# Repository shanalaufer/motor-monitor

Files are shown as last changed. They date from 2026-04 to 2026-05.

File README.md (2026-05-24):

# Motor Health Monitor
### AI-powered predictive maintenance system for electric motors


👉 [API docs (Swagger UI)](https://motor-fault-api-f7r8.onrender.com/docs)

---

## What this is

An end-to-end system that detects motor bearing faults before they cause failure. It collects vibration data from an accelerometer, extracts signal features using FFT-based processing, and runs a machine learning model to classify motor health in real time — displayed on a live web dashboard.

This is the same concept used in industrial predictive maintenance systems at manufacturing plants, wind farms, and data centers — where unplanned motor failures can cost thousands of dollars per minute of downtime.

---

## Live demo

👉 [Open the live dashboard](https://motor-monitor-gtmdausuctqgflvd5xteux.streamlit.app/)

Use the sidebar to switch between healthy and faulty motor modes and watch the FFT, health score, and status banner update in real time.

---

## System architecture
```
Vibration sensor (MPU-6050)
        ↓
Edge node (ESP32) — samples at 500Hz over I2C
        ↓
Feature extraction — FFT, RMS, crest factor, fault frequency energy
        ↓
REST API (FastAPI) — hosted on Render
        ↓
Random Forest + Autoencoder — dual model inference
        ↓
Live dashboard (Streamlit Cloud) — health score, signal plots, alerts
```

---

## Key results

- 96.7% accuracy (RF) and 90.0% accuracy (AE) on 297 real motor samples
- Health score drops from 95-100% to 0-43% when physical imbalance introduced
- Top features: crest_factor (31%), RMS (30%)
- Fault detection latency: <2 seconds from sensor to alert
- Autoencoder trained on healthy samples only — detects faults via reconstruction error
- 3-axis preprocessing: Butterworth bandpass (10-200Hz) + Welch PSD axis selection

---
## Model comparison — Random Forest vs Autoencoder

| | Random Forest | Autoencoder |
|---|---|---|
| Type | Supervised | Unsupervised |
| Training data needed | Labeled healthy + faulty | Healthy only |
| Accuracy | 96.7% | 90.0% |
| Missed faults | 0 | 0 |
| False alarms | 0 | 1 |
| Faulty error ratio | N/A | 36.9x higher than healthy |

**Key insight:** The autoencoder was trained only on healthy samples — it never saw a single fault example. Yet it detected faulty motors with high accuracy because the reconstruction error for faulty signals was significantly higher than healthy signals.

**Reconstruction error ratio after retraining (v1 model — historical):**
After collecting more healthy data (48 → 106 samples) and retraining, the ratio dropped from 66x to 36.9x — but the system became significantly more reliable on the live motor. Healthy reconstruction error dropped from 0.53 to 0.18, meaning the model learned a tighter, more accurate definition of normal. The tradeoff between sensitivity and false alarm rate is a core challenge in anomaly detection — more healthy data improved real-world reliability at the cost of a slight reduction in the error ratio.

**Unexpected finding:** Energy at 100Hz was actually higher in healthy motors (0.385) than faulty ones (0.290) — the opposite of what simulation predicted. Real motor behavior doesn't always match simulation assumptions. This is why collecting real labeled data matters.

**Why the autoencoder matters for real deployment:** A Random Forest requires fault examples to train on — meaning you need to wait for something to break or deliberately damage equipment. The autoencoder only needs normal operation data, which every system already has from day one.

## API layer

The system runs as three separate services communicating through a REST API:
ESP32 → receiver.py → POST /predict → api.py → stores result
↓
dashboard.py → GET /health every 2s → live display

**API endpoints:**

| Endpoint | Method | What it does |
|---|---|---|
| `/` | GET | Confirms API is running |
| `/health` | GET | Returns latest motor reading |
| `/history` | GET | Returns last 100 readings |
| `/predict` | POST | Accepts features, runs both models, returns results |
| `/faults` | GET | Returns all fault detection events |
| `/trends?hours=24` | GET | Average health scores over a time period |
| `/stats` | GET | Total readings, fault counts, first/last reading time |
| `/export/csv` | GET | Download full history as CSV |

**How to run the system:**

The API is deployed on Render at: https://motor-fault-api-f7r8.onrender.com

To run the system:
- python3 receiver.py — streams ESP32 data to the hosted API
- streamlit run dashboard.py — starts the local dashboard

**Dashboard modes:**
- **Live sensor** — reads from ESP32 via receiver.py → api.py
- **Simulation** — generates signals locally, sends through API for prediction

## How it works

**Signal processing:**
Motor vibration is sampled at 500Hz across all 3 axes (X, Y, Z), preprocessed with DC offset removal, a Butterworth bandpass filter (10-200Hz), and Welch PSD axis selection. The FFT decomposes the raw signal into frequency components — a healthy motor shows one dominant peak at its rotation frequency (50Hz). Motor imbalance creates energy at harmonics of the rotation frequency (100Hz, 150Hz) and elevated crest factor — detected by the ML model in real time. Five features are extracted from each signal window: RMS amplitude, peak value, crest factor, and energy at 50Hz, 100Hz, and 150Hz.

**Machine learning:**
A Random Forest classifier (100 trees) was trained on 1000 labeled samples — 500 healthy, 500 faulty — with an 80/20 train/test split. The model outputs a fault probability which is converted to a 0-100% health score. The model was chosen for its interpretability and robustness on small tabular datasets.

**Why crest factor matters:**
Bearing faults create sharp impact spikes in the vibration signal. Crest factor (peak ÷ RMS) is sensitive to these spikes — a healthy motor has a crest factor around 1.4, while an impact-type fault can push it above 3.0. This is a standard diagnostic metric in industrial vibration analysis.

---
## Hardware integration

The system runs on an ESP32-WROOM microcontroller connected to an MPU-6050 MEMS accelerometer over I2C. The ESP32 samples vibration at 500Hz and streams data over WiFi to the Python pipeline in real time.

**Hardware stack:**
- ESP32-WROOM — microcontroller running MicroPython, handles I2C and WiFi
- MPU-6050 — 3-axis MEMS accelerometer, mounted directly on motor body
- L298N — motor driver module, controls DC motor speed and direction
- Small DC hobby motor — test subject for vibration analysis

**PCB Design:**
Custom PCB designed in KiCad to replace the breadboard prototype. The schematic includes all three main components (ESP32-WROOM-32E, MPU-6050, L298N) with proper decoupling capacitors and power distribution. KiCad design files are included in the `motor monitor pcb/` folder.

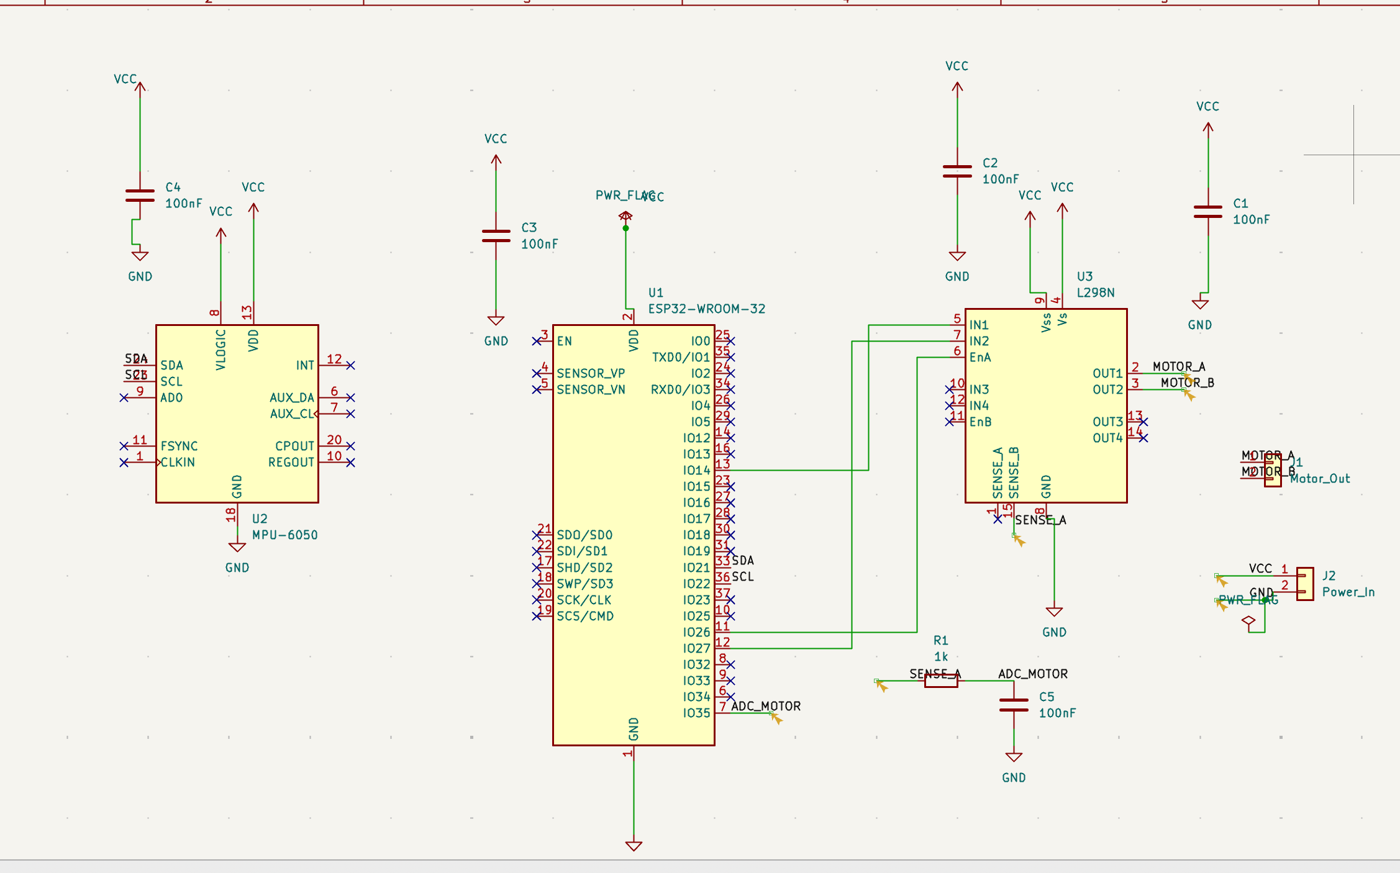
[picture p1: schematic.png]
Schematic


**Signal conditioning:**
A hardware RC anti-aliasing filter (R = 10kΩ, C = 68nF, fc = 234Hz) sits between the sensor output and the ESP32 ADC input. This prevents frequency aliasing by attenuating signals above the Nyquist frequency (250Hz at 500Hz sampling rate) before digitization — a problem that cannot be corrected in software after sampling. This complements the software Butterworth bandpass filter in the preprocessing pipeline. Two-stage filtering: hardware prevents aliasing, software removes noise.

**What I learned from real hardware:**

The sim-to-real gap is real. The simulation-trained model performed reasonably on real data but highlighted two key challenges:

1. **Gravity offset** — the accelerometer measures 1g of gravity as a DC offset that needed to be removed before feature extraction using mean subtraction
2. **Fault signature differences** — simulated bearing faults (clean 120Hz sine wave) don't perfectly match real imbalance faults, which show up more in crest factor than in fault frequency energy

**Update:** Real labeled data was collected from the physical motor — 66 healthy samples and 57 faulty samples (imbalance created by asymmetric mass on shaft). Model retrained on real data achieved 100% accuracy with crest factor as the most important feature.

## Results on real hardware

**Healthy motor:** 95-100% health score consistently with sensor mounted on motor body

**Fault detection:** Physical imbalance (asymmetric mass on shaft) successfully detected — system flagged FAULT DETECTED with health score dropping significantly

**Key finding — sim-to-real gap:** Original model trained on simulated 120Hz bearing fault signal did not generalize to real imbalance faults. Real imbalance creates energy at harmonics of rotation frequency (100Hz, 150Hz) and elevated crest factor — not a clean 120Hz signal. Model was retrained with updated imbalance simulation and successfully detected real physical faults.

**Lesson:** The gap between simulation and real sensor data is a genuine engineering challenge. Gravity offset removal, consistent sensor mounting, and fault-type-specific feature engineering were all required to bridge it.

## Tech stack

| Layer | Technology |
|---|---|
| Signal processing | Python, NumPy, SciPy (FFT) |
| Machine learning | scikit-learn (Random Forest) |
| Deep learning | PyTorch (Autoencoder) |
| Edge firmware | MicroPython on ESP32 |
| Sensor | MPU-6050 accelerometer over I2C |
| Backend API | FastAPI |
| Database | SQLite (via Render) |
| Dashboard | Streamlit |
| Deployment | Streamlit Cloud + Render |

---

## Project structure
```
motor-monitor/
├── signal_sim.py          # Signal simulation and FFT visualization
├── generate_dataset.py    # Dataset generation (1000 labeled samples)
├── train_model.py         # Model training and evaluation (simulation)
├── train_real.py          # Retrain on real motor data
├── train_v2.py            # Retrain on preprocessed 3-axis data
├── receiver.py            # Receives ESP32 data, runs ML model
├── dashboard.py           # Live Streamlit dashboard
├── preprocessor.py        # 3-axis preprocessing pipeline
├── autoencoder.py         # PyTorch autoencoder training
├── api.py                 # FastAPI backend
├── motor_dataset.csv      # Generated training dataset
├── real_data.csv          # Real motor sensor data (labeled)
├── real_data_v2.csv       # 297 samples (202 healthy + 95 faulty)
├── raw_healthy.npy        # Raw 3-axis healthy bursts
├── raw_faulty.npy         # Raw 3-axis faulty bursts
├── motor_model.pkl        # Trained Random Forest model
├── autoencoder.pth        # Trained autoencoder weights
├── scaler.pkl             # Feature scaler for autoencoder
├── motor_model_v2.pkl         # RF v2 model
├── autoencoder_v2.pth         # AE v2 weights
├── scaler_v2.pkl              # Feature scaler v2
├── autoencoder_threshold_v2.pkl  # AE threshold v2
└── requirements.txt       # Python dependencies

```
---

## Testing & reliability

The project includes a full automated test suite covering the live API, the preprocessing pipeline, and the ML models — 121 tests across three files. Tests run against the real deployed API on Render and against locally loaded model files, so they catch both integration regressions and model behaviour changes. All three suites pass cleanly and can be run independently or together.

| Test file | Tests | Covers |
|---|---|---|
| `test_api.py` | 39 | All API endpoints — status codes, response shape, field validation, fault classification correctness, DB persistence, CSV export |
| `test_preprocessor.py` | 49 | Raw data shape, DC removal, bandpass filter passband/stopband behaviour, axis selection, feature extraction correctness, CSV output |
| `test_models.py` | 33 | Model loading, RF output format, accuracy regression, feature importance, autoencoder forward pass, reconstruction error ratio, scaler behaviour |

**Signal quality monitoring**

`receiver.py` validates every incoming burst across 6 checks before it reaches the feature extraction pipeline. A burst that fails any check is logged and discarded — it is never posted to the API. This prevents corrupted or disconnected-sensor data from polluting the database or triggering false fault alerts.

- **Too short** — fewer than 64 samples on any axis
- **Flat signal / sensor disconnect** — standard deviation below 0.001 on all three axes simultaneously
- **Excessive noise** — RMS above 20.0 on any axis
- **Clipping** — more than 5% of samples at the ADC's min or max value
- **NaN or Inf** — any non-finite value anywhere in the burst
- **Sampling instability** — burst length deviates more than 10% from the expected 256 samples

**Structured logging**

`receiver.py` logs every event to both stdout and a rotating log file (`receiver.log`) using Python's built-in `logging` module. Each line is timestamped with log level — `INFO` for normal operation, `WARNING` for QC skips and API errors, `ERROR` for main loop exceptions. The file handler rotates at 1MB and keeps 3 backups, so it never fills the disk on a long-running deployment.

**Run all tests:**
```bash
pytest test_api.py test_preprocessor.py test_models.py -v
```

---

## Project roadmap

### Phase 1 — Proven prototype (complete)
- Signal simulation and FFT feature extraction
- Random Forest classifier — 100% accuracy on simulated data
- Streamlit dashboard deployed publicly
- ESP32 + MPU-6050 hardware integration
- Real data collection and model retraining on physical motor
- PyTorch autoencoder — 99% accuracy, unsupervised anomaly detection
- FastAPI REST backend — dual model inference pipeline

### Phase 2 — Better signal pipeline (complete)
- ✅ Hardware validation — test live dashboard with ESP32
- ✅ 3-axis raw data collection (202 healthy + 95 faulty)
- ✅ Butterworth bandpass filter + Welch PSD preprocessing
- ✅ Retrained RF (96.7%) and AE (90.0%) on clean preprocessed data
- ✅ KiCad custom PCB design

### Phase 3 — Product-like system (in progress)
- ✅ Deploy FastAPI to cloud (Render)
- ✅ Update public Streamlit URL to use hosted API
- ✅ Database backend — every prediction persisted to `motor_readings.db` on Render
- ✅ `GET /faults` — all fault detection events
- ✅ `GET /trends?hours=24` — average health over a time period
- ✅ `GET /stats` — total readings, fault counts, first/last reading time
- ✅ `GET /export/csv` — download full history as CSV
- ✅ Dashboard sidebar buttons to load stats, fault log, and 24hr trends
- Multi-node support — monitor multiple motors simultaneously

### Phase 4 — Advanced engineering (future)
- Multiple fault types — bearing defect, imbalance, misalignment
- Multiclass classification
- LLM natural language interface via Anthropic API

---

## Background

Built as a portfolio project to demonstrate the intersection of electrical engineering and machine learning. Predictive maintenance is one of the most widely deployed industrial AI applications — the same signal processing and anomaly detection concepts used here are applied at scale in manufacturing, energy, and aerospace.

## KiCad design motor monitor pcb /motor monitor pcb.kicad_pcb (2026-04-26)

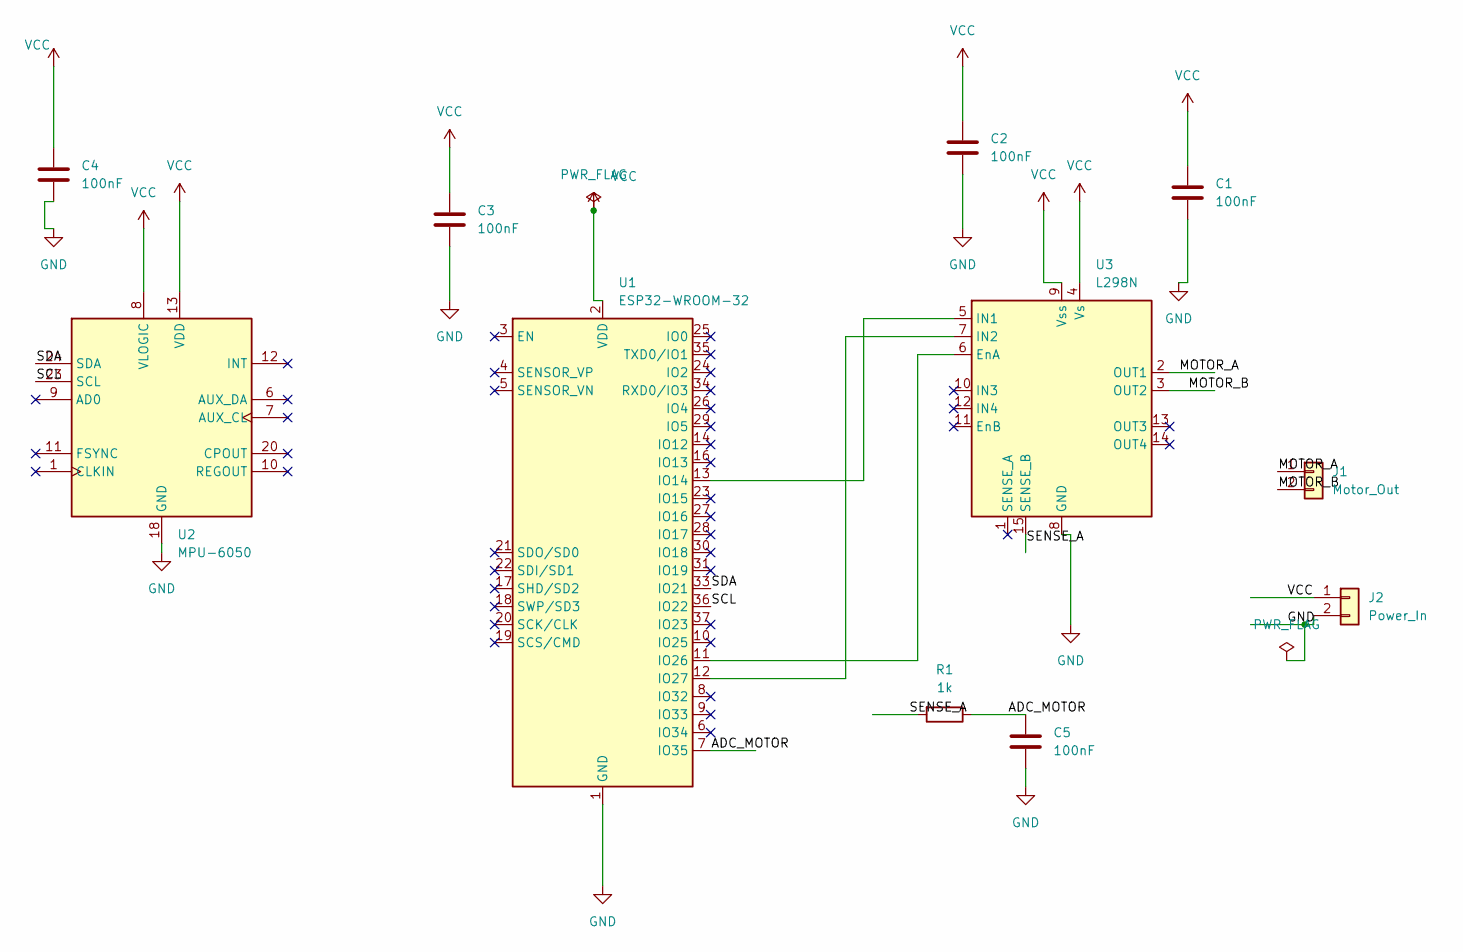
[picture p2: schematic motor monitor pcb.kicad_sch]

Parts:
C1, C2, C3, C4, C5: 100nF; C_Disc_D5.0mm_W2.5mm_P5.00mm
J1: Motor_Out; PinHeader_1x02_P2.54mm_Vertical
J2: Power_In; PinHeader_1x02_P2.54mm_Vertical
R1: 1k; R_Axial_DIN0207_L6.3mm_D2.5mm_P10.16mm_Horizontal
U1: ESP32-WROOM-32
U2: MPU-6050; InvenSense_QFN-24_4x4mm_P0.5mm
U3: L298N; TO-220-15_P2.54x5.08mm_StaggerOdd_Lead4.58mm_Vertical

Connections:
/ADC_MOTOR: C5.1, R1.1, U1.7 (IO35)
/MOTOR_A: J1.1, U3.2 (OUT1)
/MOTOR_B: J1.2, U3.3 (OUT2)
/SCL: U1.36 (IO22), U2.23 (SCL)
/SDA: U1.33 (IO21), U2.24 (SDA)
/SENSE_A: R1.2, U3.15 (SENSE_B)
GND: C1.2, C2.2, C3.2, C4.2, C5.2, J2.2, U1.1 (GND), U1.15 (GND), U1.38 (GND), U1.39 (GND), U2.18 (GND), U3.8 (GND)
unnamed: U1.13 (IO14), U3.5 (IN1)
unnamed: U1.11 (IO26), U3.6 (EnA)
unnamed: U1.12 (IO27), U3.7 (IN2)
VCC: C1.1, C2.1, C3.1, C4.1, J2.1, U1.2 (VDD), U2.8 (VLOGIC), U2.13 (VDD), U3.4 (Vs), U3.9 (Vss)

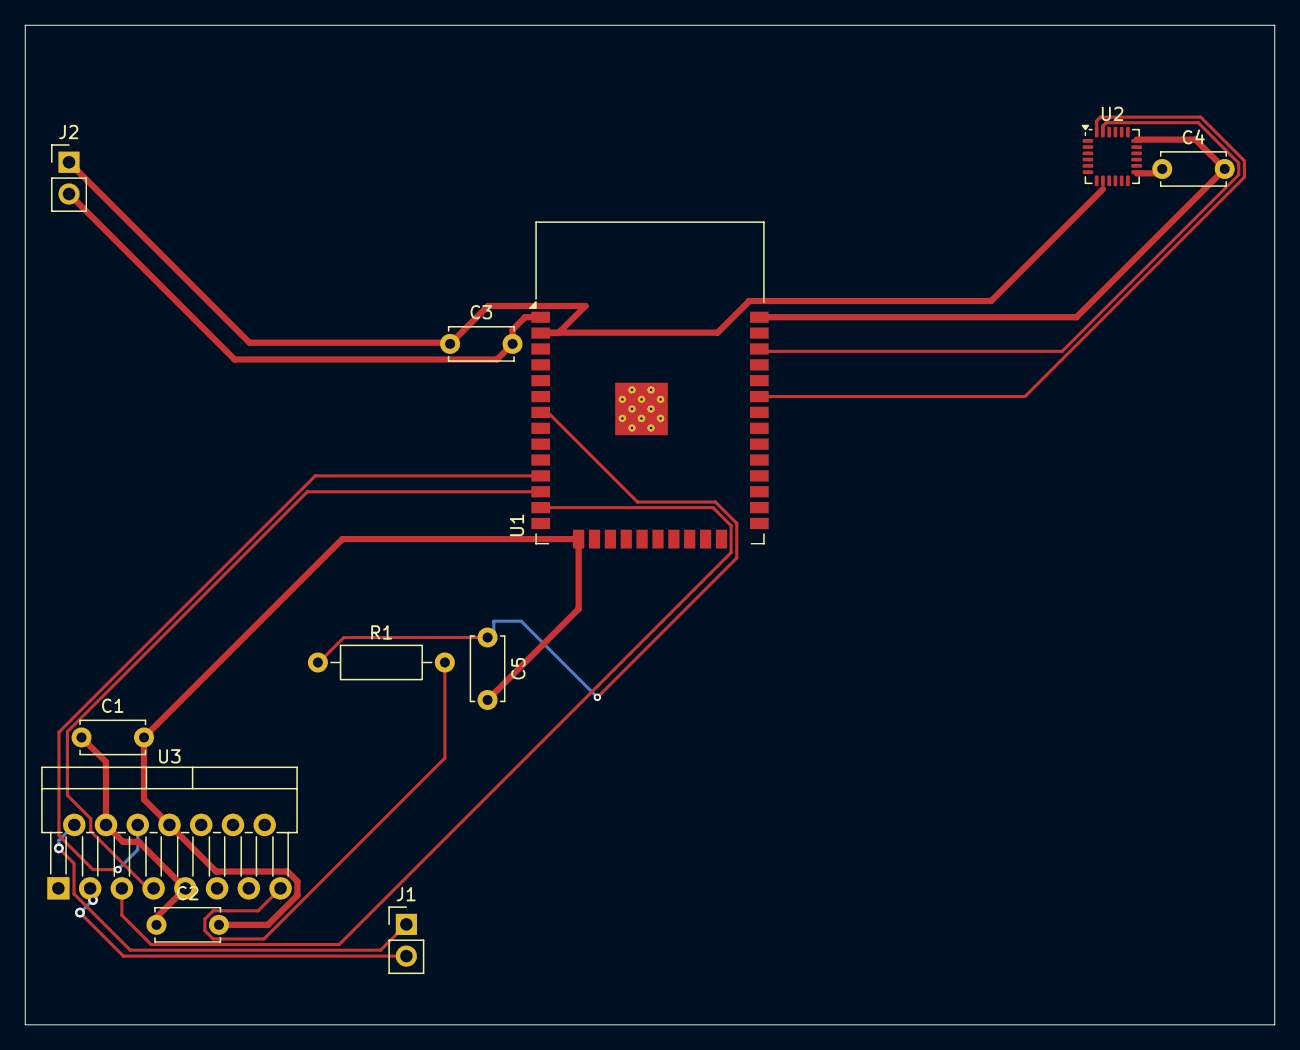
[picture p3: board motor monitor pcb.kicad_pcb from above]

Board: 2 copper layers, 100.0 x 80.0 mm, 11 parts (0 on the bottom side), 11 nets.

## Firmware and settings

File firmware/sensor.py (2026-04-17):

import struct
import time
import network
import socket
import json
from machine import I2C, Pin, PWM

# I2C setup
i2c = I2C(0, scl=Pin(22), sda=Pin(21), freq=400000)

# Wake up MPU-6050
i2c.writeto_mem(104, 0x6B, b'\x00')

# Set sample rate to 1000Hz
i2c.writeto_mem(104, 0x19, b'\x00')

def read_accel():
    raw = i2c.readfrom_mem(104, 0x3B, 6)
    x, y, z = struct.unpack('>3h', raw)
    return x / 16384.0, y / 16384.0, z / 16384.0

def collect_samples(n=256):
    samples_x, samples_y, samples_z = [], [], []
    for _ in range(n):
        try:
            x, y, z = read_accel()
            samples_x.append(x)
            samples_y.append(y)
            samples_z.append(z)
        except:
            samples_x.append(0.0)
            samples_y.append(0.0)
            samples_z.append(0.0)
        time.sleep_us(2000)
    return samples_x, samples_y, samples_z

# WiFi connection
sta = network.WLAN(network.STA_IF)
sta.active(True)
if not sta.isconnected():
    import wifi
    wifi.connect_wifi('L231 WiFi', '9175970278')

print('Sensor ready. IP:', sta.ifconfig()[0])

# Motor control - auto start
in1 = Pin(14, Pin.OUT)
in2 = Pin(27, Pin.OUT)
ena = PWM(Pin(26), freq=1000)
in1.value(1)
in2.value(0)
ena.duty(1023)
print('Motor spinning!')

# Main loop
while True:
    try:
        samples_x, samples_y, samples_z = collect_samples(256)
        payload = {
            'samples_x': samples_x,
            'samples_y': samples_y,
            'samples_z': samples_z,
            'pwm_duty': 1023
        }
        data = json.dumps(payload)
        s = socket.socket()
        s.settimeout(5)
        addr = socket.getaddrinfo('MacBook-Pro.local', 5001)[0][-1]
        s.connect(addr)
        
        # Send in chunks
        encoded = data.encode()
        s.sendall(encoded)
        s.close()
        print('Sent', len(samples_x), 'samples per axis')
        
    except Exception as e:
        print('Error:', e)
        try:
            s.close()
        except:
            pass
        time.sleep(2)
    
    time.sleep(1)

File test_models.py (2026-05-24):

"""
test_models.py — Model regression tests for Motor Monitor
Runs locally against v2 model files and real_data_v2.csv.

Usage:
    pytest test_models.py -v

Requires in the same directory:
    motor_model_v2.pkl, scaler_v2.pkl,
    autoencoder_v2.pth, autoencoder_threshold_v2.pkl,
    real_data_v2.csv
"""

import pytest
import numpy as np
import pandas as pd
import joblib
import torch
import torch.nn as nn

FEATURE_COLS = ['rms', 'peak', 'crest_factor', 'energy_50hz', 'energy_100hz', 'energy_150hz']


# ── Model definitions (must match api.py exactly) ────────────────────────────

class Autoencoder(nn.Module):
    def __init__(self, input_dim=6, bottleneck=3):
        super().__init__()
        self.encoder = nn.Sequential(
            nn.Linear(input_dim, 12), nn.ReLU(),
            nn.Linear(12, bottleneck), nn.ReLU()
        )
        self.decoder = nn.Sequential(
            nn.Linear(bottleneck, 12), nn.ReLU(),
            nn.Linear(12, input_dim)
        )
    def forward(self, x):
        return self.decoder(self.encoder(x))


# ── Fixtures ─────────────────────────────────────────────────────────────────

@pytest.fixture(scope="module")
def rf_model():
    return joblib.load('motor_model_v2.pkl')

@pytest.fixture(scope="module")
def scaler():
    return joblib.load('scaler_v2.pkl')

@pytest.fixture(scope="module")
def threshold():
    return joblib.load('autoencoder_threshold_v2.pkl')

@pytest.fixture(scope="module")
def autoencoder(threshold):
    model = Autoencoder()
    model.load_state_dict(torch.load('autoencoder_v2.pth', weights_only=True))
    model.eval()
    return model

@pytest.fixture(scope="module")
def csv_data():
    return pd.read_csv('real_data_v2.csv')

@pytest.fixture(scope="module")
def healthy_samples(csv_data):
    return csv_data[csv_data['label'] == 0][FEATURE_COLS].reset_index(drop=True)

@pytest.fixture(scope="module")
def faulty_samples(csv_data):
    return csv_data[csv_data['label'] == 1][FEATURE_COLS].reset_index(drop=True)


# ── Helper ────────────────────────────────────────────────────────────────────

def ae_recon_error(autoencoder, scaler, features_df):
    scaled = scaler.transform(features_df)
    tensor = torch.FloatTensor(scaled)
    with torch.no_grad():
        reconstructed = autoencoder(tensor)
        errors = nn.MSELoss(reduction='none')(reconstructed, tensor).mean(dim=1)
    return errors.numpy()


# ── 1. Model loading ──────────────────────────────────────────────────────────

class TestModelLoading:
    def test_rf_loads(self, rf_model):
        assert rf_model is not None

    def test_scaler_loads(self, scaler):
        assert scaler is not None

    def test_threshold_loads(self, threshold):
        assert threshold is not None

    def test_autoencoder_loads(self, autoencoder):
        assert autoencoder is not None

    def test_threshold_is_positive(self, threshold):
        assert float(threshold) > 0, f"Threshold must be positive, got {threshold}"

    def test_rf_has_expected_feature_count(self, rf_model):
        assert rf_model.n_features_in_ == 6, (
            f"RF expects {rf_model.n_features_in_} features, expected 6"
        )

    def test_scaler_has_expected_feature_count(self, scaler):
        assert scaler.n_features_in_ == 6

    def test_autoencoder_in_eval_mode(self, autoencoder):
        assert not autoencoder.training, "Autoencoder should be in eval mode"


# ── 2. Random Forest — output format ─────────────────────────────────────────

class TestRFOutputFormat:
    def test_predict_returns_array(self, rf_model, healthy_samples):
        preds = rf_model.predict(healthy_samples.iloc[:5])
        assert isinstance(preds, np.ndarray)

    def test_predict_proba_shape(self, rf_model, healthy_samples):
        proba = rf_model.predict_proba(healthy_samples.iloc[:5])
        assert proba.shape == (5, 2), f"Expected (5,2), got {proba.shape}"

    def test_probabilities_sum_to_1(self, rf_model, healthy_samples):
        proba = rf_model.predict_proba(healthy_samples.iloc[:10])
        sums = proba.sum(axis=1)
        assert np.allclose(sums, 1.0, atol=1e-6), f"Probabilities don't sum to 1: {sums}"

    def test_predictions_are_binary(self, rf_model, csv_data):
        preds = rf_model.predict(csv_data[FEATURE_COLS])
        unique = set(preds)
        assert unique <= {0, 1}, f"Unexpected prediction values: {unique}"


# ── 3. Random Forest — accuracy regression ───────────────────────────────────

class TestRFAccuracyRegression:
    def test_overall_accuracy_above_threshold(self, rf_model, csv_data):
        """RF v2 achieved 96.7% on real data — must stay above 90%."""
        X = csv_data[FEATURE_COLS]
        y = csv_data['label']
        preds = rf_model.predict(X)
        accuracy = (preds == y).mean()
        assert accuracy >= 0.90, (
            f"RF accuracy dropped below 90%: {accuracy:.1%}"
        )

    def test_healthy_recall(self, rf_model, healthy_samples, csv_data):
        """RF must correctly identify at least 85% of healthy samples."""
        true_labels = csv_data[csv_data['label'] == 0]['label'].values
        preds = rf_model.predict(healthy_samples)
        recall = (preds == 0).mean()
        assert recall >= 0.85, (
            f"Healthy recall too low: {recall:.1%} (expected >= 85%)"
        )

    def test_fault_recall(self, rf_model, faulty_samples, csv_data):
        """RF must correctly identify at least 85% of faulty samples."""
        preds = rf_model.predict(faulty_samples)
        recall = (preds == 1).mean()
        assert recall >= 0.85, (
            f"Fault recall too low: {recall:.1%} (expected >= 85%)"
        )

    def test_healthy_not_all_predicted_faulty(self, rf_model, healthy_samples):
        """Sanity check — model hasn't collapsed to always predicting fault."""
        preds = rf_model.predict(healthy_samples)
        fault_rate = (preds == 1).mean()
        assert fault_rate < 0.5, (
            f"RF flagging {fault_rate:.1%} of healthy samples as faults"
        )

    def test_faulty_not_all_predicted_healthy(self, rf_model, faulty_samples):
        """Sanity check — model hasn't collapsed to always predicting healthy."""
        preds = rf_model.predict(faulty_samples)
        healthy_rate = (preds == 0).mean()
        assert healthy_rate < 0.5, (
            f"RF classifying {healthy_rate:.1%} of faulty samples as healthy"
        )


# ── 4. Random Forest — feature importance ────────────────────────────────────
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

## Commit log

2026-03-18 Phase 1 and 2 complete — signal simulation, dataset, ML model, and dashboard
2026-03-19 Pin altair to compatible version
2026-03-27 Add real hardware integration — ESP32 + MPU-6050 sensor reading live data
    [motor_dataset.csv]
2026-03-29 Real sensor data flowing — ESP32 + MPU-6050 sending live vibration readings to ML pipeline
2026-03-30 Add hardware integration — ESP32 + MPU-6050 streaming real data
    - sensor.py auto-starts motor on boot
    - receiver.py removes gravity offset and saves real data to CSV
    - README documents sim-to-real gap and hardware stack
    [real_data.csv]
2026-03-30 Update fault model — imbalance simulation with 100Hz and 150Hz harmonics, retrain
    [motor_dataset.csv]
2026-04-05 Add real motor data — first successful fault detection
    [real_data.csv]
2026-04-10 Retrain model on real motor data — 100% accuracy on physical imbalance detection
    [real_data.csv]
2026-04-10 Add PyTorch autoencoder — 99% accuracy unsupervised, faulty error 66x higher than healthy
2026-04-12 Clean up README — fix architecture, sampling rate, tech stack, project structure, roadmap heading
2026-04-13 Add KiCad PCB schematic, screenshot, and README documentation including anti-aliasing filter design
    [motor monitor pcb.kicad_sch]
2026-04-15 Add PCB layout - components placed
    Footprints assigned, board outline set, all components
    placed and ready for routing. Schematic also finalized
    with RC anti-aliasing filter added.
    [motor monitor pcb.kicad_pcb, motor monitor pcb.kicad_sch]
2026-04-16 Add ESP32 firmware files in firmware/ folder
2026-04-17 Retrain autoencoder with more healthy data — 96% accuracy, fix AE false positives on live motor
    [real_data.csv]
2026-04-17 Update README with retrained autoencoder results — 96% accuracy, 36.9x ratio
2026-04-17 Add 3-axis data collection and preprocessing pipeline foundation - sensor.py: stream X, Y, Z axes instead of Z only - receiver.py: parse 3-axis payload, save to raw_healthy.npy/raw_faulty.npy, log to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
    [real_data_v2.csv]
2026-04-24 Collect 3-axis raw motor data: 202 healthy + 95 faulty bursts
    [real_data_v2.csv]
2026-04-24 Upgrade to v2 models: 3-axis preprocessed data, RF 96.7%, AE 90.0%
    [real_data_v2.csv]
2026-04-25 PCB routing in progress
    [motor monitor pcb.kicad_pcb]
2026-04-26 fixes in pcb layout
    [motor monitor pcb.kicad_pcb]
2026-05-24 Add automated API test suite — 39 tests across all endpoints
2026-05-24 Add preprocessing validation test suite — 49 tests covering pipeline, filter, and feature extraction
2026-05-24 Add model regression test suite — 33 tests covering RF, autoencoder, scaler, and model consistency
2026-05-24 Add signal quality monitoring layer to receiver.py — 6 checks, QC stats, skip reporting
2026-05-24 Add structured logging to receiver.py — timestamps, log levels, rotating file handler
2026-05-24 Add Testing & Reliability section to README — 121 tests, QC monitoring, structured logging
